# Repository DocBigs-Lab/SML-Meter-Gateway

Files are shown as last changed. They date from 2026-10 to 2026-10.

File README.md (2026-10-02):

<p align="center">
  DocBigsLab Logo
</p>

# DocBigsLab – SML Meter Gateway (ESP32-C3)

Fertiges Gerät am Zähler

Für **SGM-DD** Smart-Grid-Vierleiterzähler und andere Zähler, deren
IR-Schnittstelle die gleiche Bauform hat – der Lesekopf ist mechanisch
genau darauf zugeschnitten. Voraussetzung ist der aktivierte Push-Modus
(der Zähler sendet kontinuierlich das komplette Datenpaket, ohne Anfrage).

**🚀 [Firmware per Web-Installer flashen](https://docbigs-lab.github.io/SML-Meter-Gateway/)** – direkt im Browser, ohne Tools ([Details](#installation)).

> **PIN-Freigabe:** Viele Zähler (u. a. EFR SGM-D/-DD) geben die
> vollständigen Daten erst nach Eingabe der PIN am Gerät frei. Ohne PIN
> kommt oft nur der Zählerstand, aber keine weiteren Daten. 
> Die PIN gibt es beim Messstellenbetreiber.

## Übersicht

| Funktion | Status |
|---|---|
| IEC 62056-21 D0-Polling | ✅ (benötigt TX zum Zähler, s. u.) |
| SML/DSS-Push (Mode D) | ✅ |
| OLED (SSD1315 I²C) | ✅ |
| MQTT (256dpi) | ✅ |
| Home Assistant Auto-Discovery | ✅ |
| Universelle JSON-Topic | ✅ |
| Captive-Portal (AP) | ✅ |
| NVS-Persistenz | ✅ |
| MQTT-Commands (poll, reboot, config) | ✅ |
| Eindeutige Geräte-ID (Multi-Gateway-fähig) | ✅ |
| Boot-/Verbindungs-Log seriell | ✅ |
| Touch-gesteuerte Display-Anzeige | ✅ |

## Verdrahtung (ESP32-C3 DevKitM-1)

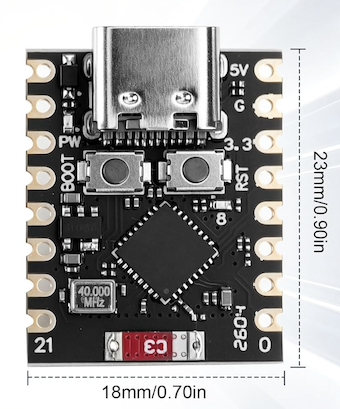
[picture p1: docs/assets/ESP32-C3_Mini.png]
ESP32-C3


| GPIO | Funktion | Verbunden mit |
|---|---|---|
| 3V3 | Versorgung 3.3V | IR-Lesekopf, OLED, Touch-Modul |
| GND | Masse | IR-Lesekopf, OLED, Touch-Modul |
| GPIO4 | UART1_RX (`CFG_CH1_RX`) | IR-Lesekopf TX |
| GPIO7 | UART1_TX (`CFG_CH1_TX`) *(optional)* | IR-Lesekopf RX |
| GPIO6 | I²C SDA (`CFG_I2C_SDA`) | OLED SDA |
| GPIO5 | I²C SCL (`CFG_I2C_SCL`) | OLED SCL |
| GPIO3 | Touch-Eingang (`CFG_TOUCH_PIN`) | Touch-Modul OUT |

```
IR-TTL-Lesekopf → ESP32-C3
  3.3V          → 3V3
  GND           → GND
  RX (Zähler)   → GPIO4   (UART1_RX, CFG_CH1_RX)
  TX (ESP)      → GPIO7   (UART1_TX, CFG_CH1_TX)  [optional, s. u.]

SSD1315 OLED I²C (0.96", oft als "SSD1306" verkauft — Chip-Aufdruck prüfen!)
  GND           → GND
  VCC (3.3V)    → 3V3 (nicht 5V — ESP32-C3-GPIOs sind 3.3V-only)
  SDA           → GPIO6   (CFG_I2C_SDA)
  SCL           → GPIO5   (CFG_I2C_SCL)

Touch-Modul (TTP223 o.ä., digitaler HIGH/LOW-Ausgang)
  GND           → GND
  VCC (3.3V)    → 3V3
  OUT           → GPIO3   (CFG_TOUCH_PIN)
```

<p align="center">
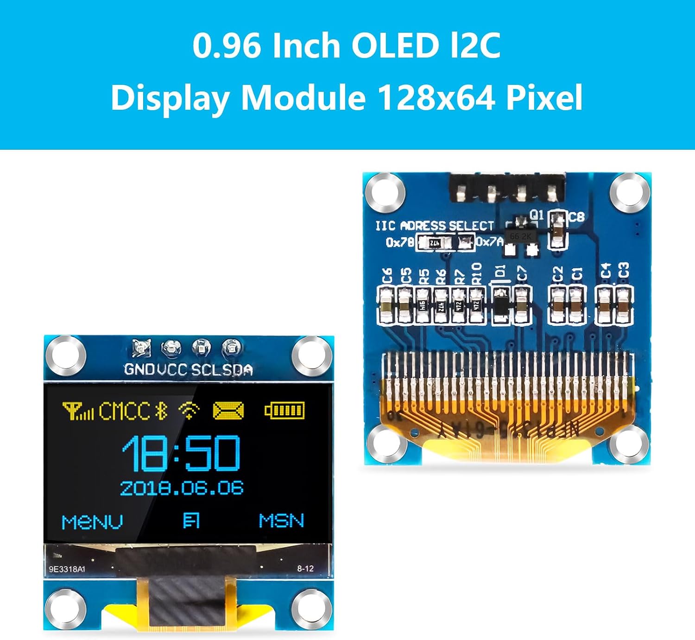
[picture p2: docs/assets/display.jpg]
OLED-Display 0,96" I²C, 128×64 Pixel
  
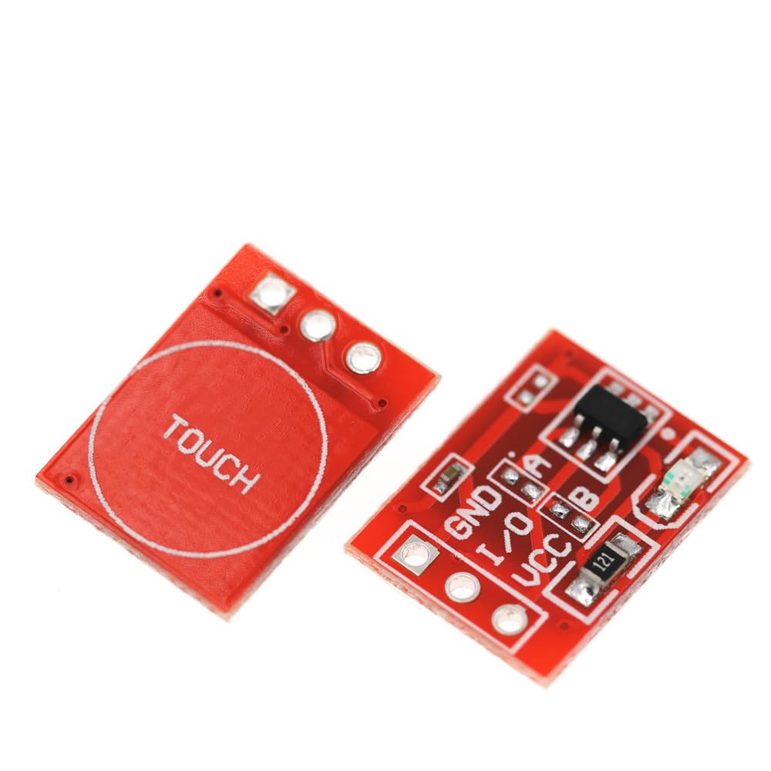
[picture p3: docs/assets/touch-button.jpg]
Touch-Modul TTP223
  
</p>
<p align="center"><em>Links: OLED-Display 0,96" (I²C, 128×64) · Rechts: Touch-Modul TTP223</em></p>

> **TX zum Zähler ist optional:** Wird nur für den D0-Polling-Modus
> benötigt, um den Zähler mit `/?!\r\n` zur Datenübertragung
> aufzufordern. Im SML/DSS-Push-Modus (Mode D) sendet der Zähler von
> sich aus, ohne Anfrage nötig. Für dieses Gerät wird kein Schreiben
> auf den Zähler benötigt.

> **Lesekopf:** Schaltung, Funktionsweise und Platine des verwendeten
> Lesekopfs sind in [docs/lesekopf.md](docs/lesekopf.md) beschrieben, das
> 3D-gedruckte Gehäuse in [docs/gehaeuse.md](docs/gehaeuse.md).

> **OLED-Adresse:** Der Code prüft fest I2C-Adresse `0x3C` (Standard bei
> den meisten Modulen). Manche sind auf `0x3D` gestrappt — im Log erscheint
> dann `[OLED] Kein Display an I2C 0x3C gefunden`.

> **Touch/Display-Verhalten:** Der ESP32-**C3** hat keine eigene
> Touch-Sensor-Hardware (anders als klassischer ESP32/S2/S3) — deshalb ein
> externes TTP223-Modul statt `touchRead()`. Das OLED läuft im
> Normalbetrieb standardmäßig im Stromsparmodus (aus). Direkt nach dem
> Boot bleibt es großzügige 60s an, damit Status-Meldungen lesbar sind.
> Danach: Touch weckt es auf und zeigt den ersten Wert (Leistung) groß;
> weiterer Touch schaltet durch (Leistung → Bezug → Einspeisung →
> Spannung → Strom → Frequenz → von vorn). Der angezeigte Wert wird nur
> beim Touch aktualisiert, nicht laufend (kein Flackern). Ohne erneuten
> Touch geht es nach "Touch-Display-Timeout" (im Portal einstellbar,
> Default 10s) wieder aus.

> Die Pins sind Defaults aus `main.cpp` und lassen sich per `build_flags` in
> `platformio.ini` überschreiben (z. B. `-DCFG_CH1_RX=n`).

## Installation

### 🚀 Web-Installer (empfohlen)

Firmware direkt im Browser flashen – kein Tool, keine Kommandozeile:

👉 **[Web-Installer starten](https://docbigs-lab.github.io/SML-Meter-Gateway/)**

1. ESP32-C3 per USB anschließen.
2. Seite in **Chrome oder Edge** öffnen (Firefox und Safari können kein
   Web Serial) und auf „Firmware jetzt flashen" klicken.
3. Port auswählen, Installation bestätigen – danach geht es mit der
   [Ersten Inbetriebnahme](#erste-inbetriebnahme) weiter.

> Bei der Erstinstallation fragt der Installer, ob der Flash gelöscht
> werden soll – für ein neues Gerät ja. Bei einem **Update** nein: dann
> bleiben WLAN- und MQTT-Einstellungen erhalten.
>
> Wird kein Port angezeigt oder bricht die Verbindung ab: BOOT-Taster
> gedrückt halten, kurz RESET drücken, BOOT loslassen und erneut
> versuchen.

### Selbst bauen (PlatformIO)

```bash
pio run -t upload
pio device monitor
```

Jeder Build legt über `build_installer.py` die Flash-Teile unter
`docs/firmware/` ab und aktualisiert `docs/manifest.json` mit der Version
aus `FW_VERSION` – der Web-Installer liefert also immer den zuletzt
committeten Build aus.

> **ESP32-C3 nativer USB-Port:** `upload_speed = 115200` ist in
> `platformio.ini` bewusst gesetzt. Mit der esptool-Default-Baudrate bricht
> der Flash-Vorgang über den nativen USB-CDC-Port auf diesem Board oft
> reproduzierbar ab („chip stopped responding"). Bei Upload-Problemen:
> anderes/kürzeres USB-Kabel, direkt in einen Mac/PC-Port (kein Hub), und
> beim Verbindungsaufbau ggf. den BOOT-Taster gedrückt halten.

## Erste Inbetriebnahme

1. Gerät ohne gespeichertes WLAN (Default-SSID `changeme`) → startet AP
   `SGM-Setup-C3` (PW `sgm12345`).
2. Im Browser: `http://192.168.4.1` (öffnet sich auf den meisten Geräten
   automatisch als Captive-Portal-Hinweis).
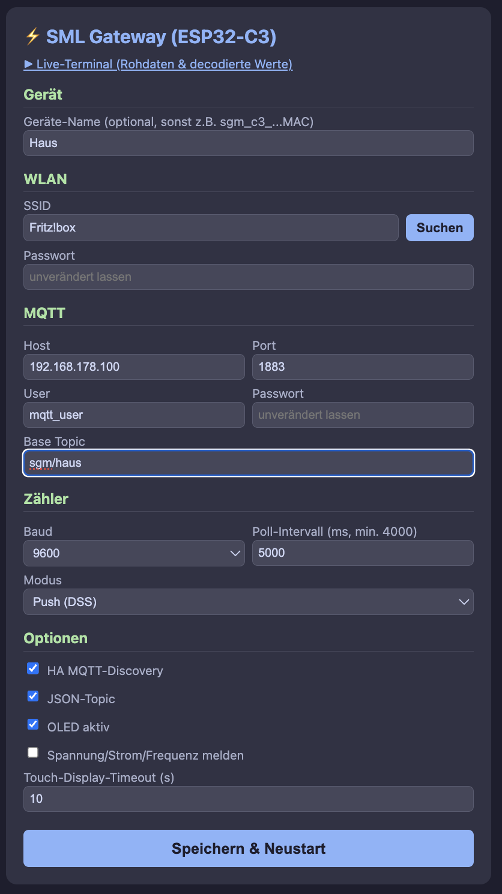
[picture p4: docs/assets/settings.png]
Einstellungsseite
   
3. Im Formular: WLAN (per „Suchen" lassen sich Netze in Reichweite samt
   Signalstärke auflisten und per Klick übernehmen — praktisch, um die
   Empfangsqualität am Einbauort zu prüfen; unter ca. −75 dBm wird es
   wackelig), MQTT-Broker, Base-Topic, Baudrate, Poll-Intervall
   (min. 4000 ms — kürzere Werte haben keine Wirkung, da ein Frame-Read
   intern bis zu 4 s dauert), Modus, HA-Discovery, OLED. WLAN-/MQTT-Passwort
   werden aus Sicherheitsgründen nie vorausgefüllt — leer lassen heißt
   „unverändert".
4. Speichern → Gerät startet neu, verbindet sich und pusht.

### Einstellungen nachträglich ändern

Das Web-Portal läuft auch im normalen Betrieb und ist jederzeit unter der
IP des Gateways erreichbar (`http://<IP>/`). Die IP steht im Serial-Log
beim Boot, in der Router-Übersicht (Hostname `sgm-gateway-c3`) und ist
in Home Assistant auf der Geräteseite mit dem „Besuchen-Button" direkt 
aufrufbar.

Kommt das Gerät nicht ins WLAN (falsche Zugangsdaten, Router getauscht),
startet es nach 15 s Verbindungsversuch automatisch das AP-Portal
`SGM-Setup-C3` – dann wie bei der Ersteinrichtung vorgehen. Ist der
MQTT-Broker 5 Minuten lang nicht erreichbar, passiert dasselbe.

Verbindet sich 3 Minuten lang niemand mit dem Portal, startet das Gerät
neu und versucht das gespeicherte WLAN erneut. So findet es nach einem
Stromausfall (Router bootet langsamer als der ESP) oder einem
Broker-Neustart von selbst zurück in den Normalbetrieb. Ist noch kein
WLAN konfiguriert, bleibt das Portal dauerhaft offen.

**Notlösung, falls die IP unbekannt ist:** per MQTT

```
Topic:   smarthome/sgm/cmd/config
Payload: beliebig (z. B. "1")
```

veröffentlichen. Das Gerät startet neu und geht ins AP-Portal, auch wenn
die WLAN-Verbindung funktionieren würde.

## Serial-Diagnose (115200 Baud)

Beim Boot wird der Verbindungsstatus mitgeloggt:

```
[BOOT] ESP32-C3 startet...
[CFG] Geraete-ID=sgm_c3_xxxxxxxxxxxx SSID='...' MQTT=host:port Topic='...'
[WIFI] Verbinde mit SSID '...' ...
[WIFI] verbunden, IP=192.168.x.x
[MQTT] Verbinde zu host:port ...
[MQTT] verbunden als 'sgm_c3_xxxxxxxxxxxx'
```

Schlägt WLAN fehl, erscheint stattdessen `[WIFI] Verbindung fehlgeschlagen
(status=...)` gefolgt von `[AP] Captive-Portal gestartet: ...`. Schlägt MQTT
fehl: `[MQTT] Verbindung fehlgeschlagen (error=..., returnCode=...)` (Codes
aus der `lwmqtt`-Bibliothek, z. B. Broker nicht erreichbar oder
Zugangsdaten falsch).

## MQTT-Topics

Basistopic `smarthome/sgm` (konfigurierbar):

| Topic | Inhalt |
|---|---|
| `smarthome/sgm/status` | online/offline (retained, LWT) |
| `smarthome/sgm/power_w` | Leistung [W] |
| `smarthome/sgm/import_kwh` | Import [kWh] |
| `smarthome/sgm/export_kwh` | Export [kWh] |
| `smarthome/sgm/total_kwh` | Gesamt [kWh] |
| `smarthome/sgm/voltage_v` | Spannung [V] |
| `smarthome/sgm/current_a` | Strom [A] |
| `smarthome/sgm/json` | Vollständiges JSON-Paket |

### Commands (veröffentlichen auf)

| Topic | Wirkung |
|---|---|
| `smarthome/sgm/cmd/poll` | Sofortiges Polling |
| `smarthome/sgm/cmd/reboot` | Neustart |
| `smarthome/sgm/cmd/config` | Neustart, erzwingt beim nächsten Boot das AP-Config-Portal (`SGM-Setup-C3`), unabhängig vom WLAN-Status — Notlösung, falls die IP des Web-Portals unbekannt ist |

## Home Assistant

Mit aktivierter HA-Discovery erscheinen die Sensoren automatisch, benannt
nach der geräteeigenen, aus der Efuse-MAC abgeleiteten ID (`sgm_c3_xxxx…`,
siehe Serial-Log beim Boot) — dadurch kollidieren mehrere Gateways am
selben MQTT-Broker nicht miteinander. Auf der Geräteseite in HA stehen
Hersteller, Modell (`SML Meter Gateway (ESP32-C3)`) und Firmware-Version
(`FW_VERSION`, per `build_flags` überschreibbar), dazu ein Link „Besuchen"
direkt zum Web-Portal des Gateways. Folgende Sensoren werden angelegt:
- Power (W)
- Import, Export, Gesamt (kWh) — mit `state_class: total_increasing`,
  landet automatisch im HA-Energie-Dashboard
- Spannung (V), Strom (A)

Alternativ manuell in `configuration.yaml`:
```yaml
mqtt:
  sensor:
    - name: SGM Power
      state_topic: "smarthome/sgm/power_w"
      unit_of_measurement: "W"
      device_class: power
    - name: SGM Import
      state_topic: "smarthome/sgm/import_kwh"
      unit_of_measurement: "kWh"
      device_class: energy
      state_class: total_increasing
```

## OBIS-Referenz

| OBIS | Bedeutung |
|---|---|
| `1-0:7.7.0` | Aktive Leistung |
| `0-0:1.8.0` | Gesamtenergie |
| `0-0:1.8.1` | Import |
| `0-0:1.8.2` | Export |
| `1-0:24.7.0` | Spannung |
| `1-0:31.7.0` | Strom |
| `0-0:32.0.0` | Netzfrequenz |

> ⚠️ Die OBIS-Codes für Spannung (`1-0:24.7.0`) und Netzfrequenz
> (`0-0:32.0.0`) weichen von den in der Praxis gebräuchlichen
> Standard-OBIS-Kennzahlen ab (üblich wären eher `1-0:32.7.0` bzw.
> `1-0:14.7.0`). Kann herstellerspezifisch beim SGM-D/DigiMeto korrekt
> sein — bitte gegen echte Serial-Logs vom eigenen Zähler verifizieren,
> bevor man sich auf diese beiden Werte verlässt.

## Projektstruktur

```
sml-meter-gateway/
├── platformio.ini       # Build-Config, Pins, lib_deps, upload_speed
├── build_installer.py   # Post-Build: Flash-Teile + manifest.json für den Web-Installer
├── README.md
├── LICENSE              # MIT
├── docs/
│   ├── index.html        # Web-Installer (GitHub Pages, ESP Web Tools)
│   ├── manifest.json     # Installer-Manifest (automatisch erzeugt)
│   ├── firmware/         # Flash-Teile für den Installer (automatisch erzeugt)
│   ├── stls/             # STL-Dateien für das 3D-gedruckte Gehäuse
│   ├── lesekopf.md       # Schaltung und Aufbau des IR-Lesekopfs
│   ├── gehaeuse.md       # 3D-gedrucktes Gehäuse
│   └── assets/           # Bilder (Installer-Seite, Lesekopf, Gehäuse)
└── src/
    └── main.cpp          # Komplette Firmware (einzige Source-Datei)
```

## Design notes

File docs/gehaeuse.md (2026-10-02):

# Gehäuse

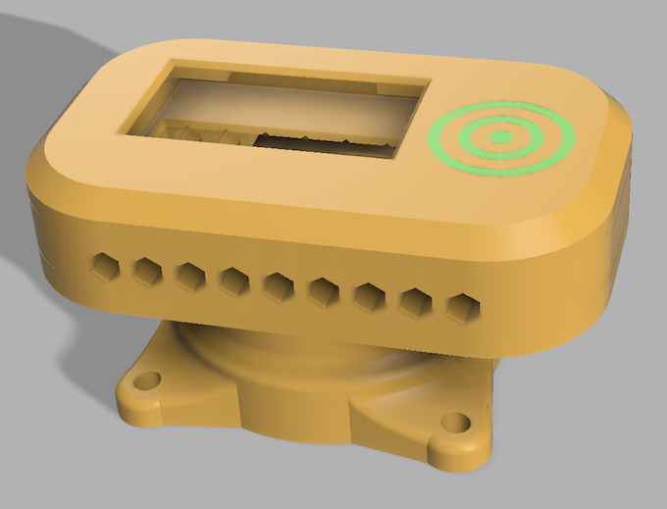
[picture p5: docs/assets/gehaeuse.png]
Gehäuse

*Gehäuse*

Das Gehäuse wurde in Fusion konstruiert. Es besteht aus vier Einzelteilen, die sich einfach per 3D-Druck herstellen lassen:

- oberer Deckel
- Mittelteil
- unterer Deckel
- Sockel

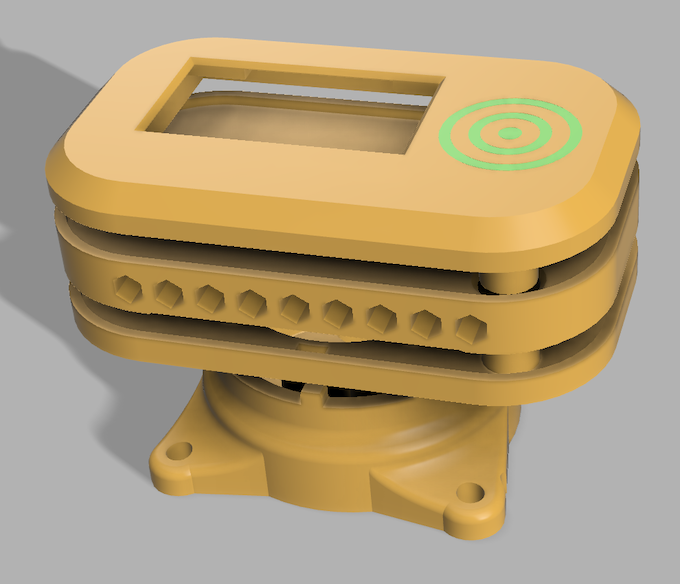
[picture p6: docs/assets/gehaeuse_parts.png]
Einzelteile des Gehäuses

*Einzelteile des Gehäuses*

## Hinweise zum Druck

- Einige Teile brauchen teilweise Stützstrukturen.
- Beim Sockel muss an entsprechender Stelle eine Druckpause gesetzt werden, um den Ringmagneten (Außen-Ø 27 mm, Innen-Ø 16 mm, Höhe 5 mm) zur Befestigung einzulegen. Bei welcher Schicht die Pause liegt, hängt von der im Slicer eingestellten Schichthöhe ab.
- Der Sockel wird anschließend mit Sekundenkleber mit dem unteren Deckel verklebt.

## STL-Dateien
tedfy1-porqaR-morwam
| Teil | Datei |
|---|---|
| oberer Deckel | [Deckel-oben.stl](stls/Deckel-oben.stl) |
| Mittelteil | [Mittelteil.stl](stls/Mittelteil.stl) |
| unterer Deckel | [Deckel-unten.stl](stls/Deckel-unten.stl) |
| Sockel | [Sockel.stl](stls/Sockel.stl) |

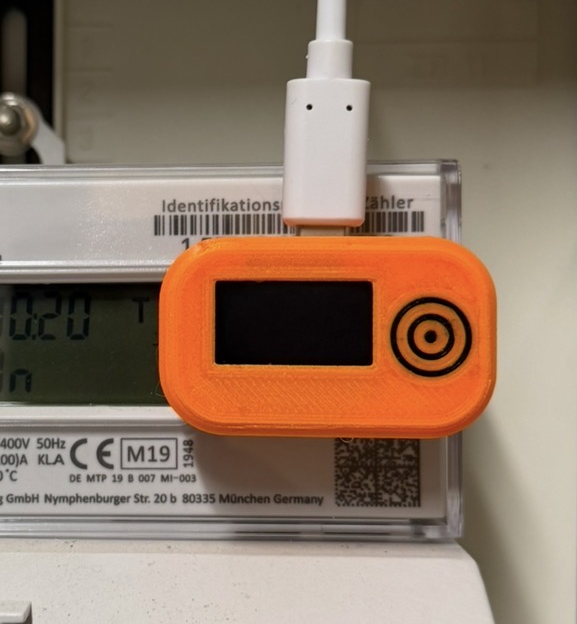
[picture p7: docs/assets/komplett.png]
Fertiges Gerät am Zähler

*Fertiges Gerät im Einsatz am Zähler*

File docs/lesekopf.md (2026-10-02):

# Lesekopf für Stromzähler – Schaltungsbeschreibung

Ein zweistufiger IR-Empfänger zur optischen Auslesung der D0-/SML-Schnittstelle (OBIS-Daten) von Stromzählern, abgeleitet vom Volkszähler-Referenzdesign.

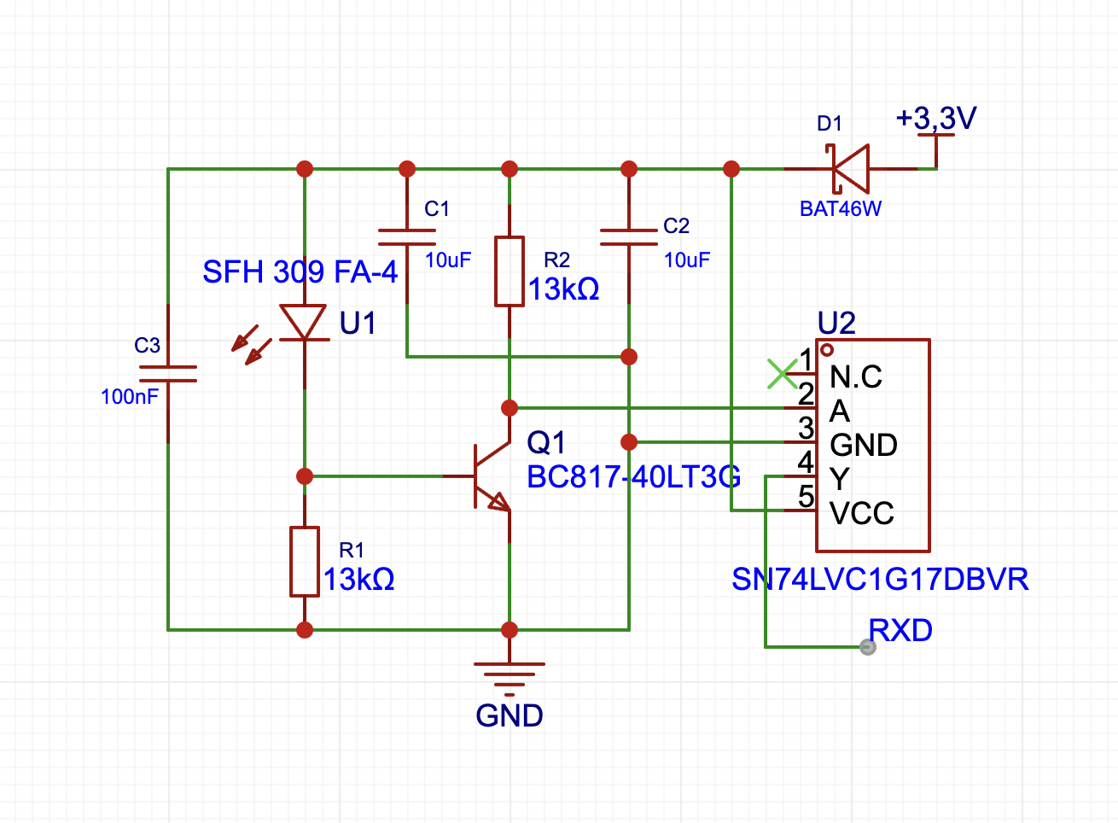
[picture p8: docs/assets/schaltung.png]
Schaltplan des Lesekopfs

*Schaltplan (Fototransistor, Verstärkerstufe, Schmitt-Trigger)*

---

## 1. Funktionsprinzip

Der Signalweg gliedert sich in drei Stufen:

### 1.1 Fotoempfänger (U1, R1, C3)

Der **SFH309FA-4** ist ein NPN-Fototransistor mit Tageslichtsperrfilter. Er arbeitet mit **R1 (13 kΩ)** als Lastwiderstand: Trifft ein IR-Impuls der Zähler-LED auf, fließt ein Fotostrom, der über R1 einen Spannungsabfall erzeugt. Der Tageslichtsperrfilter hält dabei sichtbares Umgebungslicht weitgehend fern.

### 1.2 Verstärker-/Schaltstufe (Q1, R2)

Der **BC817-40** arbeitet als invertierender Verstärker in Emitterschaltung mit **R2 (13 kΩ)** als Kollektorwiderstand. Aufgaben dieser Stufe:

- Verstärkung des kleinen, trägen Spannungshubs des Fototransistors auf einen großen, fast rail-to-rail Hub
- Durch die Verstärkung schaltet der Transistor schnell zwischen Sättigung und Sperrung – das macht die Flanke am Kollektor deutlich steiler als am reinen Fototransistor-Ausgang

### 1.3 Signalaufbereitung (U2 – SN74LVC1G17)

Ein **Schmitt-Trigger-Buffer**, der aus der noch nicht perfekten Flanke von Q1 einen sauberen digitalen Pegel mit definierter Schalt-Hysterese formt und direkt den **RXD**-Eingang des Mikrocontrollers treibt.

Zusätzlich:
- **D1 (BAT46W)** – Schottky-Diode zur Entkopplung/Schutz der 3,3-V-Versorgung
- **C3 (100 nF)** – Entkopplung der Versorgung: fängt schnelle Spannungsspitzen ab, direkt zwischen Versorgung und GND
- **C1, C2 (10 µF)** – Pufferung der Versorgung gegen langsamere Einbrüche, z. B. beim Umschalten von Q1 und U2

---

## 2. Warum reicht ein einfacher Fototransistor an einem GPIO nicht?

Die Lösung "einfacher Fototransistor direkt an einen GPIO" ist in der Community sehr verbreitet, weil sie auf den ersten Blick einfach und günstig wirkt. In der Praxis macht sie aber sehr schnell Probleme und stellt keine zufriedenstellende Lösung dar, sobald es um die zuverlässige Auslesung der OBIS-Daten geht.

Bei der Auslesung der optischen Schnittstelle wird nicht nur gezählt, sondern eine **serielle Bitfolge** übertragen – nach DIN EN 62056-21 (D0-Schnittstelle) mit 300–9600 Baud, bzw. bei modernen Zählern direkt als **SML-Telegramm** mit den OBIS-Kennzahlen.

Ein UART-Empfänger tastet das Signal in der Mitte jedes festen Bit-Zeitfensters ab (bei 9600 Baud ca. alle 104 µs). Das stellt hohe Anforderungen an Flankensteilheit und Signalqualität:

| Problem am nackten Fototransistor | Auswirkung bei UART/OBIS |
|---|---|
| Träge, lineare Flanke (parasitäre Sperrschichtkapazität, kleiner Fotostrom) | Startbit-Erkennung verspätet sich → gesamtes Abtastraster verschiebt sich |
| Spannungshub abhängig von Lichtintensität/Abstand/Alterung | Keine stabile, definierte Schaltschwelle |
| Kein Hysterese-Mechanismus | Rauschen/Fremdlicht führt zu Mehrfach-Kippen nahe der Schwelle |
| Zu langsame An-/Abstiegszeit bei schnellen Bitwechseln (`...1010101...`) | "Augenöffnung" schließt sich → Bitfehler statt nur Zählfehler |

Ein einzelnes falsch erkanntes Bit zerstört das komplette SML-Telegramm (CRC-Fehler) oder liefert falsche ASCII-Zeichen bei D0 – die OBIS-Werte sind dann unbrauchbar.

---

## 3. Warum die Schaltung das löst

- **Q1 (Verstärkerstufe):** schaltet unabhängig vom exakten Fotostrom-Pegel schnell und mit vollem Hub durch – wichtig für stabiles Bit-Timing auch bei hohen Baudraten
- **Schmitt-Trigger (74LVC1G17):** liefert Hysterese gegen Rauschen und eine konsistente Schaltschwelle mit minimaler, definierter Verzögerung – verhindert Bit-Timing-Jitter
- **Tageslichtsperrfilter (SFH309FA-4):** hält sichtbares Fremdlicht vom Sensor fern, bevor es überhaupt zu einem Störsignal wird
- **C3, C1, C2:** halten die Versorgung stabil, damit Spannungseinbrüche und -spitzen nicht als Phantom-Flanken mitten im Bitstream Störbits erzeugen

**Fazit:** Bei OBIS-Auslesung über die optische Schnittstelle ist diese Signalaufbereitung keine Komfortfunktion, sondern die Voraussetzung dafür, dass die UART überhaupt fehlerfreie Telegramme empfängt. Ein nackter Fototransistor an einem GPIO liefert bei den nötigen Baudraten keine verlässliche Bit-für-Bit-Dekodierung.

---

## 4. Platine

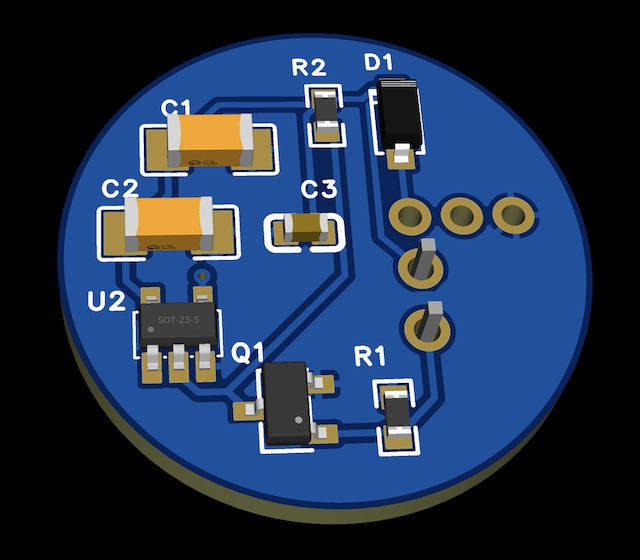
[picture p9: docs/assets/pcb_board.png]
Platine des Lesekopfs


**Lesekopf:** Es wurde eine maßgefertigte Platine in SMD Technik passend für den Lesekopf designt und gefertigt.

---

## 5. Kompletter Lesekopf

Fertiges Gerät am Zähler
*Fertig montierter Lesekopf mit Magnethalterung am Stromzähler*

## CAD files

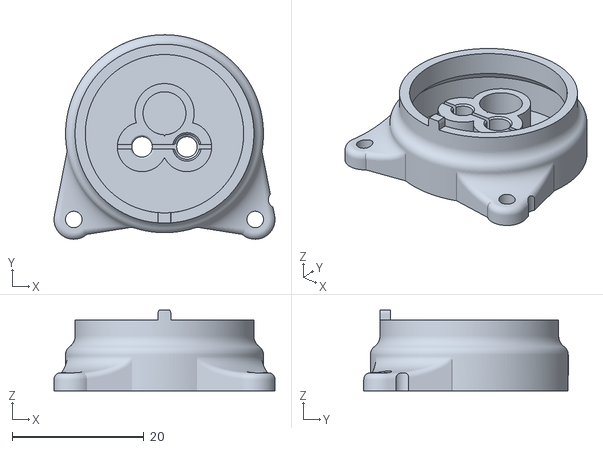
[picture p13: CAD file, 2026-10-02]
docs/stls/Sockel.stl
33.5 x 31.0 x 12.2

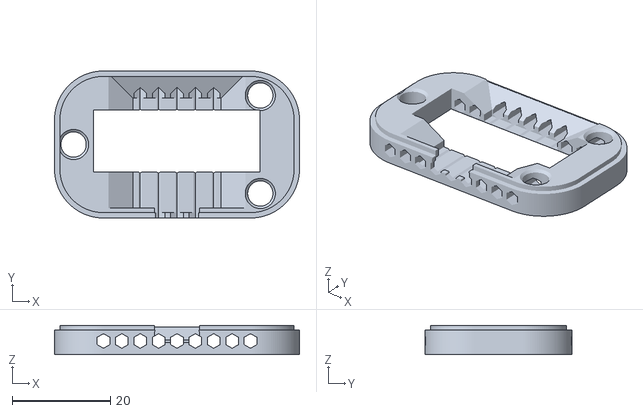
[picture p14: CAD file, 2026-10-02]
docs/stls/Mittelteil.stl
50.0 x 30.0 x 6.00

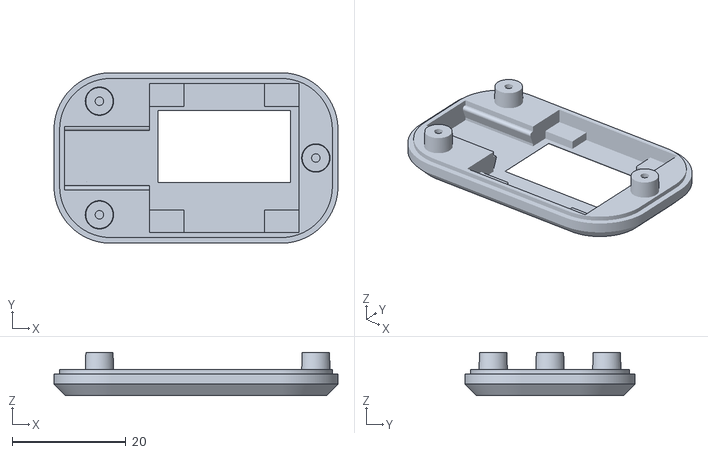
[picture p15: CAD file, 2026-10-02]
docs/stls/Deckel-oben.stl
50.0 x 30.0 x 7.60

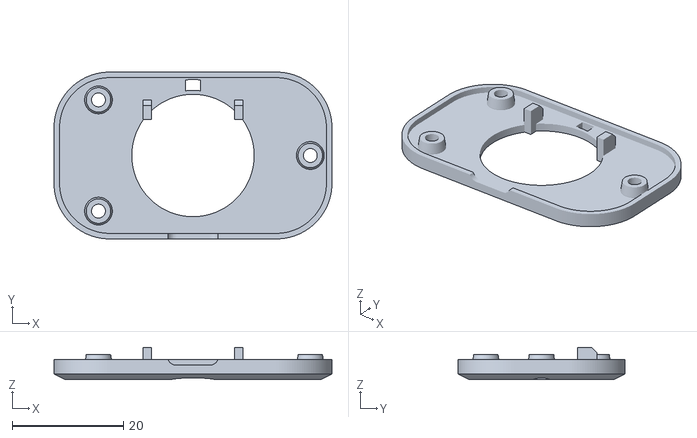
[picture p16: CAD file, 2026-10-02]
docs/stls/Deckel-unten.stl
50.0 x 30.0 x 5.80

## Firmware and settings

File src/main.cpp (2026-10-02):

// =====================================================================
//  SML Meter Gateway – ESP32-C3 · IEC 62056-21 / SML · OLED · MQTT
// =====================================================================

#include <Arduino.h>
#include <algorithm>
#include <WiFi.h>
#include <MQTT.h>
#include <ArduinoJson.h>
#include <Wire.h>
#include <U8g2lib.h>
#include <Preferences.h>
#include <DNSServer.h>
#include <AsyncTCP.h>
#include <ESPAsyncWebServer.h>

// Erscheint in HA als Firmware-Version des Geraets (Discovery "sw").
#ifndef FW_VERSION
#define FW_VERSION "1.2.3"
#endif
#define HA_MODEL "SML Meter Gateway (ESP32-C3)"

// ── Pins (ESP32-C3 optimiert) ───────────────────────────────────
#ifndef CFG_CH1_RX
#define CFG_CH1_RX  4
#endif
#ifndef CFG_CH1_TX
#define CFG_CH1_TX  7
#endif
#ifndef CFG_I2C_SDA
#define CFG_I2C_SDA 6
#endif
#ifndef CFG_I2C_SCL
#define CFG_I2C_SCL 5
#endif
#ifndef CFG_TOUCH_PIN
#define CFG_TOUCH_PIN 3
#endif

// ── Konfiguration (NVS) ─────────────────────────────────────────
struct AppConfig {
  char deviceName[33] = "";   // leer = Geraete-ID aus MAC, sonst "sgm_<name>"
  char ssid[33]      = "changeme";
  char pass[65]      = "";
  char mqttHost[33]  = "192.168.1.10";
  int  mqttPort      = 1883;
  char mqttUser[33]  = "";
  char mqttPass[33]  = "";
  char baseTopic[64] = "smarthome/sgm";
  bool haDiscovery   = true;
  bool jsonTopic     = true;
  bool oledEnabled   = true;
  bool extraSensors  = false;  // Spannung/Strom/Frequenz melden (falls Zaehler das sendet)
  int  uartBaud      = 9600;
  int  pollMs        = 5000;
  bool pushMode      = true;    // Default: SML-Push (DSS), kein Handshake noetig
  int  touchTimeoutS = 10;   // Sekunden bis Display nach letztem Touch wieder ausgeht
};

static AppConfig cfg;
static Preferences prefs;
static constexpr const char* NS = "sgmcfg";

// Frames brauchen intern bis zu 4s (Push-Modus-Timeout) — kürzere Poll-
// Intervalle hätten ohnehin keine Wirkung.
static constexpr int MIN_POLL_MS = 4000;

static void configSave() {
  prefs.begin(NS, false);
  prefs.putString("dn",   cfg.deviceName);
  prefs.putString("ssid", cfg.ssid);
  prefs.putString("pass", cfg.pass);
  prefs.putString("mh",   cfg.mqttHost);
  prefs.putInt  ("mp",   cfg.mqttPort);
  prefs.putString("mu",   cfg.mqttUser);
  prefs.putString("mpw",  cfg.mqttPass);
  prefs.putString("bt",   cfg.baseTopic);
  prefs.putInt  ("ha",   cfg.haDiscovery ? 1 : 0);
  prefs.putInt  ("js",   cfg.jsonTopic   ? 1 : 0);
  prefs.putInt  ("ol",   cfg.oledEnabled ? 1 : 0);
  prefs.putInt  ("vcf",  cfg.extraSensors ? 1 : 0);
  prefs.putInt  ("ub",   cfg.uartBaud);
  prefs.putInt  ("pm",   cfg.pollMs);
  prefs.putInt  ("pm2",  cfg.pushMode    ? 1 : 0);
  prefs.putInt  ("tts",  cfg.touchTimeoutS);
  prefs.end();
  Serial.println("[CFG] saved");
}

// Einmal-Flag: per MQTT-Befehl "cmd/config" gesetzt, erzwingt beim naechsten
// Boot das AP-Config-Portal (unabhaengig vom WLAN-Status) und wird danach
// sofort wieder geloescht.
static bool gForceAp = false;

static void requestConfigPortal() {
  prefs.begin(NS, false);
  prefs.putInt("fap", 1);
  prefs.end();
  Serial.println("[CFG] Config-Portal angefordert, starte neu...");
  delay(200);
  ESP.restart();
}

static void configLoad() {
  prefs.begin(NS, true);
  if (!prefs.isKey("ssid")) {
    prefs.end();
    configSave();
    prefs.begin(NS, true);
  }

  gForceAp = prefs.getInt("fap", 0) != 0;
  prefs.getString("dn",   cfg.deviceName, sizeof(cfg.deviceName));
  prefs.getString("ssid", cfg.ssid, sizeof(cfg.ssid));
  prefs.getString("pass", cfg.pass, sizeof(cfg.pass));
  prefs.getString("mh",   cfg.mqttHost, sizeof(cfg.mqttHost));
  cfg.mqttPort = prefs.getInt("mp", 1883);
  prefs.getString("mu",   cfg.mqttUser, sizeof(cfg.mqttUser));
  prefs.getString("mpw",  cfg.mqttPass, sizeof(cfg.mqttPass));
  prefs.getString("bt",   cfg.baseTopic, sizeof(cfg.baseTopic));
  cfg.haDiscovery = prefs.getInt("ha", 1) != 0;
  cfg.jsonTopic   = prefs.getInt("js", 1) != 0;
  cfg.oledEnabled = prefs.getInt("ol", 1) != 0;
  cfg.extraSensors = prefs.getInt("vcf", 0) != 0;
  cfg.uartBaud    = prefs.getInt("ub", 9600);
  cfg.pollMs      = prefs.getInt("pm", 5000);
  cfg.pushMode    = prefs.getInt("pm2", 1) != 0;
  cfg.touchTimeoutS = prefs.getInt("tts", 10);
  prefs.end();

  if (gForceAp) {
    prefs.begin(NS, false);
    prefs.putInt("fap", 0);
    prefs.end();
  }

  if (cfg.ssid[0] == 0)       strcpy(cfg.ssid, "changeme");
  if (cfg.mqttHost[0] == 0)   strcpy(cfg.mqttHost, "192.168.1.10");
  if (cfg.baseTopic[0] == 0)  strcpy(cfg.baseTopic, "smarthome/sgm");
  if (cfg.pollMs < MIN_POLL_MS) cfg.pollMs = MIN_POLL_MS;
  if (cfg.touchTimeoutS < 1) cfg.touchTimeoutS = 10;
}

// ── OLED: SSD1315 (vom User am Chip-Aufdruck identifiziert) ──────
// Konstruktor-Signatur ist (rotation, reset, clock, data) — reset bleibt
// U8X8_PIN_NONE, sonst faellt u8g2 intern auf Wire.begin() ohne Argumente
// (= ESP32-Default-I2C-Pins statt CFG_I2C_SDA/SCL) zurueck.
static U8G2_SSD1315_128X64_NONAME_F_HW_I2C u8g2(
  U8G2_R0, U8X8_PIN_NONE, CFG_I2C_SCL, CFG_I2C_SDA);

static constexpr uint8_t OLED_I2C_ADDR = 0x3C;
static bool oledActive = false;

// WICHTIG: kein eigener Wire.begin() vor u8g2.begin()! u8g2 ruft intern
// selbst Wire.begin(CFG_I2C_SDA, CFG_I2C_SCL) auf (via u8x8_byte_arduino_hw_i2c,
// dank korrekter Pin-Reihenfolge im Konstruktor oben) — ein zusaetzlicher
// eigener Wire.begin()-Aufruf VOR u8g2.begin() lässt den I2C-Treiber auf
// diesem ESP32-C3-Board zuverlaessig haengen (reproduziert, kein Timeout).
// Die Praesenz-Pruefung passiert deshalb NACH u8g2.begin(), nicht davor;
// u8g2.begin() liefert unabhaengig davon immer true, daher der eigene Check.
static bool dispInit() {
  u8g2.begin();
  Wire.beginTransmission(OLED_I2C_ADDR);
  if (Wire.endTransmission() != 0) {
    Serial.printf("[OLED] Kein Display an I2C 0x%02X gefunden - Anzeige deaktiviert\n",
                  OLED_I2C_ADDR);
    return false;
  }
  u8g2.setContrast(255);
  return true;
}

// true, solange ein Status-Bildschirm (Boot/MQTT/Keine Daten) statt einer
// Werteseite zu sehen ist — dann darf der naechste Poll einmalig auf die
// Werteseite wechseln. Werteseiten selbst werden nur per Touch neu gezeichnet.
static bool dispShowsStatus = false;

static void dispStatus(const char* l1, const char* l2, const char* l3) {
  dispShowsStatus = true;
  u8g2.clearBuffer();
  u8g2.setFont(u8g2_font_7x13_tr);
  u8g2.drawStr(0, 14, l1);
  u8g2.setFont(u8g2_font_6x10_tr);
  u8g2.drawStr(4, 32, l2);
  u8g2.drawStr(4, 46, l3);
  u8g2.drawHLine(0, 22, u8g2.getWidth());
  u8g2.drawHLine(0, 38, u8g2.getWidth());
  u8g2.sendBuffer();
}

// AP-Config-Portal-Anzeige: keine Ueberschrift, stattdessen die volle
// Hoehe fuer SSID/PW/IP nutzen — die stehen sonst nirgends am Geraet.
static void dispApInfo(const char* ssid, const char* pw, const char* ip) {
  u8g2.clearBuffer();
  u8g2.setFont(u8g2_font_6x10_tr);
  char buf[40];
  snprintf(buf, sizeof(buf), "SSID: %s", ssid);
  u8g2.drawStr(0, 16, buf);
  snprintf(buf, sizeof(buf), "PW:   %s", pw);
  u8g2.drawStr(0, 36, buf);
  snprintf(buf, sizeof(buf), "IP:   %s", ip);
  u8g2.drawStr(0, 56, buf);
  u8g2.sendBuffer();
}

// ── Touch-Steuerung (TTP223 o.ae., aktiv-HIGH) ────────────────────
// Display ist im Normalbetrieb per Power-Save aus; ein Touch weckt es und
// zeigt Werte gross einzeln an (durchschalten per weiterem Touch), nach
// touchTimeoutS ohne Eingabe geht es wieder aus. Direkt nach dem Booten
// gilt grosszuegig BOOT_DISPLAY_HOLD_MS, damit Status-Meldungen lesbar
// bleiben, ohne dass man dafuer touchen muss.
static constexpr uint32_t BOOT_DISPLAY_HOLD_MS = 60000;
static bool     oledOn         = false;
static bool     oledBootHold   = true;
static uint32_t oledOnSince    = 0;
static int      dispPage       = 0;
static bool     lastTouchRaw   = false;
static uint32_t lastTouchEdgeMs = 0;

// Vorwaerts-deklariert: wird auch aus smlReadFrame() heraus aufgerufen,
// damit ein Touch waehrend des bis zu 4s blockierenden SML-Reads nicht
// verloren geht (siehe pollTouch()-Definition weiter unten).
static void pollTouch();

// Vorwaerts-deklariert: fuettern das Live-Terminal (/terminal-Seite) mit
// Rohbytes bzw. decodierten Werten, werden aber schon in smlListenPush()/
// smlPollD0() aufgerufen, lange bevor der WebSocket weiter unten definiert ist.
static void wsSendRaw(const uint8_t* buf, size_t len);
static void wsSendDecoded();

// ── SML / IEC 62056-21 Parser ───────────────────────────────────
struct ParsedValue {
  char  obis[24];
  float value;
  char  unit[16];
  bool  valid;
};

static HardwareSerial meterSerial(1);
static ParsedValue gvals[24];
static int         gvalCount = 0;
static char        gIdent[64] = {};

// Liest ab buf[*pos] ein SML-TLV-Element (Octet String/Integer/Unsigned/Liste,
// binaere BER-aehnliche Kodierung: oberes Halbbyte des ersten Bytes = Typ,
// unteres Halbbyte = Laenge inkl. TL-Byte(s) bzw. bei Listen = Elementanzahl;
// Fortsetzungsbit 0x80 kettet weitere Laengen-Halbbytes an). Bewegt *pos
// hinter das komplette Element (bei Listen rekursiv ueber alle Kindelemente).
// Numerische Werte (Integer/Unsigned, <=8 Byte) werden vorzeichenrichtig in
// *outVal geschrieben, falls outVal != nullptr. Gibt bei Parse-/Bounds-Fehlern
// false zurueck.
static bool smlSkipOrRead(const uint8_t* buf, size_t len, size_t* pos, int64_t* outVal) {
  if (*pos >= len) return false;
  uint8_t tl = buf[*pos];
  uint8_t type = (tl >> 4) & 0x07;
  size_t nbits = tl & 0x0F;
  size_t tlBytes = 1;
  while (buf[*pos + tlBytes - 1] & 0x80) {
    if (tlBytes > 3 || *pos + tlBytes >= len) return false;
    nbits = (nbits << 4) | (buf[*pos + tlBytes] & 0x0F);
    tlBytes++;
  }

  if (type == 0x07) {
    // Liste: nbits ist hier die Elementanzahl, keine Byte-Laenge.
    size_t p = *pos + tlBytes;
    for (size_t i = 0; i < nbits; i++) {
      if (!smlSkipOrRead(buf, len, &p, nullptr)) return false;
    }
    *pos = p;
    return true;
  }

  if (nbits < tlBytes) return false;
  size_t dataLen = nbits - tlBytes;
  size_t dataStart = *pos + tlBytes;
  if (dataStart + dataLen > len) return false;

  if (outVal && (type == 0x05 || type == 0x06) && dataLen > 0 && dataLen <= 8) {
    int64_t v = 0;
    bool neg = (type == 0x05) && (buf[dataStart] & 0x80);
    for (size_t i = 0; i < dataLen; i++) v = (v << 8) | buf[dataStart + i];
    if (neg) v -= ((int64_t)1 << (dataLen * 8));
    *outVal = v;
  }

  *pos = dataStart + dataLen;
  return true;
}

// Durchsucht einen kompletten SML-Datensatz nach SML_ListEntry-Eintraegen
// (Muster: 0x77 = Liste mit 7 Elementen, gefolgt von 0x07 = 6-Byte-OBIS-Code).
// Pragmatischer Scan statt vollstaendigem Nachrichtenbaum-Abstieg — die
// SML_ListEntry-Struktur (objName, status, valTime, unit, scaler, value,
// valueSignature) ist an dieser Bytefolge eindeutig erkennbar.
//
// Die alten Werte werden erst hier verworfen, nicht schon zu Beginn eines
// Reads: waehrend des blockierenden smlReadFrame() laeuft pollTouch(), und
// ein Touch in diesem Fenster zeigte sonst "---" statt des letzten Werts.
static void parseSmlBinaryFrame(const uint8_t* buf, size_t len) {
  gvalCount = 0;
  for (size_t i = 0; i + 8 <= len; i++) {
    if (!(buf[i] == 0x77 && buf[i+1] == 0x07)) continue;

    unsigned a=buf[i+2], b=buf[i+3], c=buf[i+4], d=buf[i+5], e=buf[i+6];
    // Sanity-Check: echte OBIS-Codes fuer Stromzaehler haben medium (a) 0
    // (abstrakt) oder 1 (Elektrizitaet). Andere Bytefolgen (z.B. 0xFF FF...
    // aus Nachrichten-Header-Feldern wie serverId) sind zufaellige Treffer
    // auf "0x77 0x07" und keine echten ListEntries — ohne diesen Filter
    // verspringt sich der Scan an solchen Fehltreffern.
    if (a > 1) continue;
    size_t pos = i + 8;

    if (!smlSkipOrRead(buf, len, &pos, nullptr)) continue;      // status
    if (!smlSkipOrRead(buf, len, &pos, nullptr)) continue;      // valTime
    int64_t unitVal = 0;
    if (!smlSkipOrRead(buf, len, &pos, &unitVal)) continue;     // unit
    int64_t scalerVal = 0;
    if (!smlSkipOrRead(buf, len, &pos, &scalerVal)) continue;   // scaler
    int64_t rawVal = 0;
    if (!smlSkipOrRead(buf, len, &pos, &rawVal)) continue;      // value

    if (gvalCount < 24) {
      ParsedValue& v = gvals[gvalCount];
      snprintf(v.obis, sizeof(v.obis), "%u-%u:%u.%u.%u", a, b, c, d, e);
      double value = (double)rawVal * pow(10.0, (double)(int8_t)scalerVal);
      if (unitVal == 30) value /= 1000.0;  // Wh -> kWh (Energie-Register)
      v.value = (float)value;
      v.unit[0] = '\0';
      v.valid = true;
      gvalCount++;
    }
    i = pos - 1;  // hinter dieses Element springen (Schleife zaehlt selbst i++)
  }
}

static float getObis(const char* prefix, float def = NAN) {
  size_t pl = strlen(prefix);
  for (int i = 0; i < gvalCount; i++)
    if (strncmp(gvals[i].obis, prefix, pl) == 0 && gvals[i].valid)
      return gvals[i].value;
  return def;
}

static void serialClearRx(HardwareSerial& s) {
  while (s.available()) s.read();
}

// Liest einen kompletten binaeren SML-Datensatz: Start-Escape
// 1B1B1B1B01010101, danach beliebige Nutzdaten, Ende-Escape 1B1B1B1B1A
// gefolgt von 1 Fuellbyte-Zaehler + 2 CRC16-Byte. Bytes vor der Start-
// Sequenz werden verworfen (Rauschen/Reste einer vorherigen Uebertragung).
static bool smlReadFrame(uint8_t* buf, size_t cap, unsigned long timeoutMs, size_t* outLen = nullptr) {
  serialClearRx(meterSerial);
  static const uint8_t STARTSEQ[8] = {0x1B,0x1B,0x1B,0x1B,0x01,0x01,0x01,0x01};
  uint32_t t0 = millis();
  size_t idx = 0;
  bool haveStart = false;
  while (millis() - t0 < timeoutMs && idx < cap) {
    while (meterSerial.available() && idx < cap) {
      buf[idx++] = (uint8_t)meterSerial.read();

      if (!haveStart && idx >= 8 && memcmp(buf + idx - 8, STARTSEQ, 8) == 0) {
        haveStart = true;
        memcpy(buf, STARTSEQ, 8);
        idx = 8;
      }
      if (haveStart && idx >= 8) {
        size_t m = idx - 8;
        if (buf[m]==0x1B && buf[m+1]==0x1B && buf[m+2]==0x1B && buf[m+3]==0x1B && buf[m+4]==0x1A) {
          if (outLen) *outLen = idx;
          return true;
        }
      }
    }
    if (oledActive) pollTouch();
    delay(1);
  }
  if (outLen) *outLen = idx;
  return false;
}

static bool smlPollD0(unsigned long timeoutMs) {
  meterSerial.begin(300, SERIAL_7E1, CFG_CH1_RX, CFG_CH1_TX);
  delay(50);
  meterSerial.print("/?!\r\n");
  delay(300);

  char idLine[64] = {0};
  size_t idLen = 0;
  uint32_t t0 = millis();
  while (millis() - t0 < 1500 && idLen < sizeof(idLine)-1) {
    while (meterSerial.available() && idLen < sizeof(idLine)-1) {
      char c = meterSerial.read();
      if (c == '\n') break;
      if (c != '\r') idLine[idLen++] = c;
    }
    if (idLen > 0) break;
    if (oledActive) pollTouch();
    delay(10);
  }
  idLine[idLen] = '\0';

  if (idLen < 3 || idLine[0] != '/') {
    Serial.printf("[SML] Kein/ungueltiges Ident (idLen=%u, raw=\"%s\")\n",
                  (unsigned)idLen, idLine);
    meterSerial.begin(cfg.uartBaud, SERIAL_8N1, CFG_CH1_RX, CFG_CH1_TX);
    return false;
  }
  strncpy(gIdent, idLine, sizeof(gIdent)-1);
  gIdent[sizeof(gIdent)-1] = '\0';
  Serial.printf("[SML] Ident: %s\n", gIdent);

  // Handshake (300 Baud) ist klassisch 7E1, das eigentliche SML-Datenpaket
  // danach aber 8N1 (bestaetigt per Tasmota SerialConfig an diesem Zaehler).
  meterSerial.begin(cfg.uartBaud, SERIAL_8N1, CFG_CH1_RX, CFG_CH1_TX);
  delay(100);
  meterSerial.print("?0!A\r\n");

  static uint8_t frame[1024];
  size_t flen = 0;
  if (!smlReadFrame(frame, sizeof(frame), timeoutMs, &flen)) {
    Serial.println("[SML] Frame-Timeout nach Ident (kein vollstaendiger Datensatz)");
    return false;
  }

  wsSendRaw(frame, flen);
  parseSmlBinaryFrame(frame, flen);
  wsSendDecoded();
  Serial.printf("[SML] Frame geparst, %d Werte gefunden\n", gvalCount);
  return gvalCount > 0;
}

static bool smlListenPush(unsigned long timeoutMs) {
  // Bestaetigt per Tasmota SerialConfig an diesem Zaehler: 8N1, kein Handshake noetig.
  meterSerial.begin(cfg.uartBaud, SERIAL_8N1, CFG_CH1_RX, CFG_CH1_TX);
  static uint8_t frame[1024];
  size_t flen = 0;
  if (!smlReadFrame(frame, sizeof(frame), timeoutMs, &flen)) {
    // Byte-Anzahl + Anfang der Rohdaten mitloggen: 0 Bytes deutet auf
    // Verdrahtung/Lesekopf, Muell-Bytes auf falsche Baudrate/Invertierung.
    Serial.printf("[SML] Push-Modus: kein Frame empfangen (Timeout, %u Bytes)",
                  (unsigned)flen);
    for (size_t i = 0; i < flen && i < 32; i++) Serial.printf(" %02X", frame[i]);
    Serial.println();
    return false;
  }
  wsSendRaw(frame, flen);
  parseSmlBinaryFrame(frame, flen);
  wsSendDecoded();
  Serial.printf("[SML] Frame geparst, %d Werte gefunden\n", gvalCount);
  return gvalCount > 0;
}

// ── MQTT ────────────────────────────────────────────────────────
static WiFiClient net;
static MQTTClient mqtt;
static char topicAvail[96], topicJson[96], topicCmd[96];
static bool haDiscDone = false;

// Pro-Gerät eindeutige ID, damit mehrere Gateways nicht dieselben
// Home-Assistant-Entities/MQTT-Client-IDs belegen. Ohne konfigurierten
// cfg.deviceName wird sie aus der Efuse-MAC gebildet, sonst aus dem
// (auf MQTT/HA-taugliche Zeichen bereinigten) Klarnamen.
static char gDeviceId[40] = {};

static void initDeviceId() {
  if (cfg.deviceName[0]) {
    char clean[sizeof(cfg.deviceName)];
    size_t j = 0;
    for (const char* p = cfg.deviceName; *p && j < sizeof(clean) - 1; p++) {
      char c = *p;
      if (c >= 'A' && c <= 'Z') c += 'a' - 'A';
      bool ok = (c >= 'a' && c <= 'z') || (c >= '0' && c <= '9') || c == '_' || c == '-';
      clean[j++] = ok ? c : '_';
    }
    clean[j] = '\0';
    snprintf(gDeviceId, sizeof(gDeviceId), "sgm_%s", clean);
  } else {
    uint64_t mac = ESP.getEfuseMac();
    snprintf(gDeviceId, sizeof(gDeviceId), "sgm_c3_%04X%08X",
             (unsigned)(mac >> 32), (unsigned)mac);
  }
}

static void buildTopics() {
  snprintf(topicAvail, sizeof(topicAvail), "%s/status", cfg.baseTopic);
  snprintf(topicJson,  sizeof(topicJson),  "%s/json",   cfg.baseTopic);
  snprintf(topicCmd,   sizeof(topicCmd),   "%s/cmd/#",  cfg.baseTopic);
}

static unsigned long lastPoll = 0;

static void mqttCmd(MQTTClient* client, char* topic, char* payload, int len) {
  // Der Befehl wird durch das Sub-Topic bestimmt (.../cmd/poll,
  // .../cmd/reboot, .../cmd/config) — der Payload-Inhalt ist egal.
  String t(topic);
  int slash = t.lastIndexOf('/');
  String cmd = (slash >= 0) ? t.substring(slash + 1) : t;
  cmd.toLowerCase();

  if (cmd == "poll")          lastPoll = 0;
  else if (cmd == "reboot")   ESP.restart();
  else if (cmd == "config")   requestConfigPortal();
}

// Bleibt MQTT trotz funktionierendem WLAN dauerhaft unerreichbar (z.B.
// vertippte Broker-Zugangsdaten), gibt es sonst keinen Weg zurück ins
// Config-Portal ausser per USB-Reflash — cmd/config setzt ja MQTT voraus.
// Deshalb hier automatischer Fallback nach MQTT_FAIL_AP_MS.
static uint32_t mqttFailSince = 0;
static constexpr uint32_t MQTT_FAIL_AP_MS = 5UL * 60UL * 1000UL;
// Ohne Client im AP-Portal wird nach dieser Zeit neu gestartet (siehe loop()).
static constexpr uint32_t AP_IDLE_REBOOT_MS = 3UL * 60UL * 1000UL;
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
void loop() {
  if (restartPending && (int32_t)(millis() - restartAt) >= 0) ESP.restart();

  if (isApMode) {
    dnsServer.processNextRequest();
    // Rueckweg aus dem AP-Portal: nach einem Stromausfall bootet der ESP
    // meist schneller als der Router und landet sonst dauerhaft hier. Ist
    // AP_IDLE_REBOOT_MS lang kein Client verbunden, neu starten und das
    // gespeicherte WLAN erneut versuchen (nur wenn eins konfiguriert ist).
    static uint32_t apIdleSince = millis();
    if (WiFi.softAPgetStationNum() > 0) {
      apIdleSince = millis();
    } else if (strcmp(cfg.ssid, "changeme") != 0 &&
               millis() - apIdleSince > AP_IDLE_REBOOT_MS) {
      Serial.println("[AP] Kein Client im Portal - Neustart, versuche WLAN erneut");
      delay(100);
      ESP.restart();
    }
    delay(20);
    return;
  }

  mqttReconnect();
  mqtt.loop();

  if (WiFi.status() != WL_CONNECTED) {
    static uint32_t lastTry = 0;
    if (millis() - lastTry > 10000) {
      lastTry = millis();
      WiFi.reconnect();
    }
    delay(100);
    return;
  }

  if (millis() - lastPoll >= (uint32_t)cfg.pollMs) {
    lastPoll = millis();
    pollAndPublish();
  }

  if (oledActive) {
    pollTouch();

    // Auto-Off nach Timeout — direkt nach dem Boot gilt die grosszuegige
    // Haltezeit, danach der (im Portal einstellbare) kurze Touch-Timeout.
    uint32_t offDelayMs = oledBootHold ? BOOT_DISPLAY_HOLD_MS
                                        : (uint32_t)cfg.touchTimeoutS * 1000UL;
    if (oledOn && millis() - oledOnSince > offDelayMs) {
      oledOn = false;
      oledBootHold = false;
      u8g2.setPowerSave(1);
    }
  }

  delay(20);
}
